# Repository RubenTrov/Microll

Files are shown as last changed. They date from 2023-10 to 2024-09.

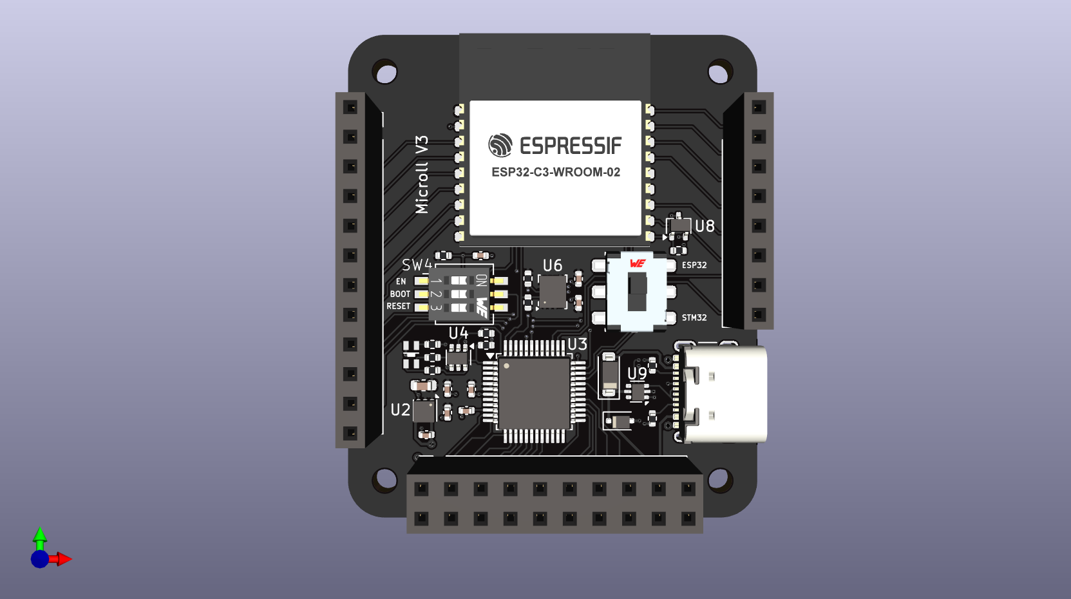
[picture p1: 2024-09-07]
Microll_3D_Front.png

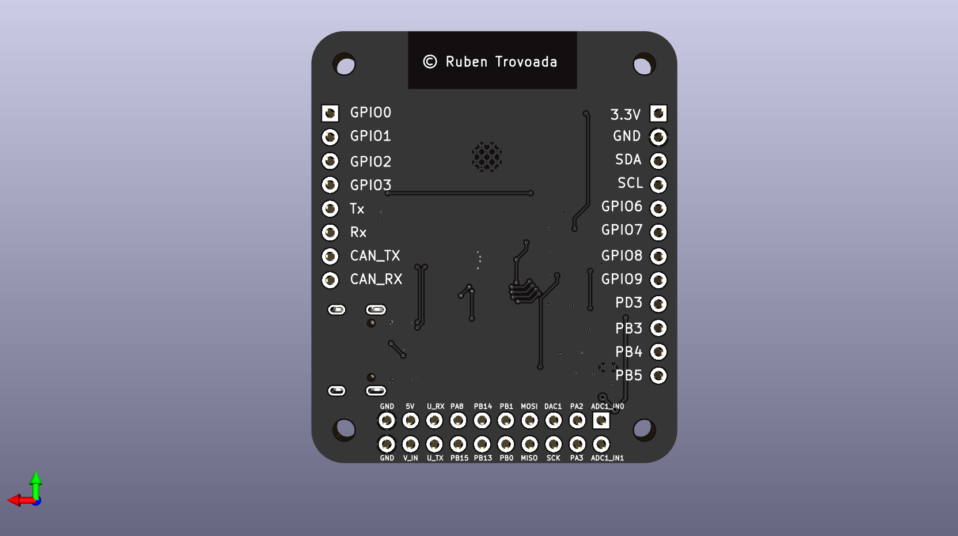
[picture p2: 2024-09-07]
Microll_3D_Back.png

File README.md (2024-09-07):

This is going to be a small PCB with a microcontroller, IMU and a form of wirelessly transmitting that information though wifi/bluetooh.
It will serve as a central piece for a lot of future IoT projects.



#How to program the PCB
This board has two microcontrollers that share the Same USB Port through a switch.
##Programming the STM32
1. The USB selector switch should be flipped to the SM32 position.
2. Open STM32CubeIDE and load the file that you wish to flash to the microcontroller.
3. Set the Boot pin High by setting the Boot on the DIP switch to position 2 and then from the ON side of the switch connect a jumper to the 3.3V GPIO header.
4. Connect the USB to the PCB to power on the board. This should make the STM32 be detected by the programmer.
5. Erase the memory and upload the file.
6. Disconnect the PCB from the USB and switch the position of Boot on the DIP switch.
7. Plug the USB back in the PCB and it will begin executing the program that was uploaded!

##Programming the ESP32
1. You may need to connect the GPIO0 pin to GND using a jumper cable before powering on the board
2. Flip the USB switch to the ESP32 position
3. Flip the EN on the DIP switch to the on position to connect it to 3.3V
4. Power on the board by plugging in the USB
5. Disconnect the GPIO0 pin from GND
6. The board should now be ready to program. Use the editor of your choice for this.

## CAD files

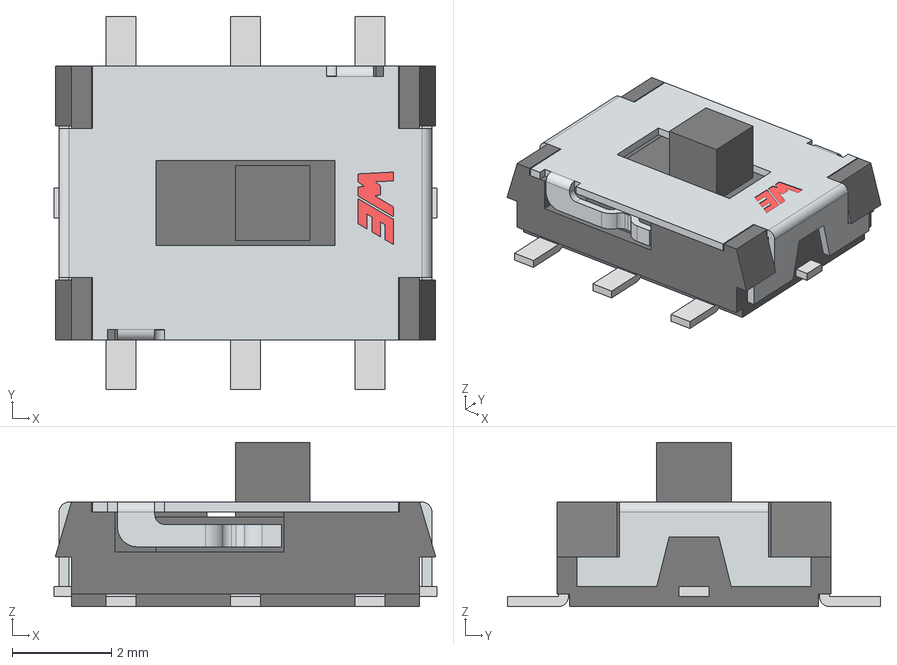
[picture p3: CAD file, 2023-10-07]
3DModels/Download_STP_452403012014 (rev1).stp
7.70 x 7.50 x 3.30 mm
Base
Actuator
cover

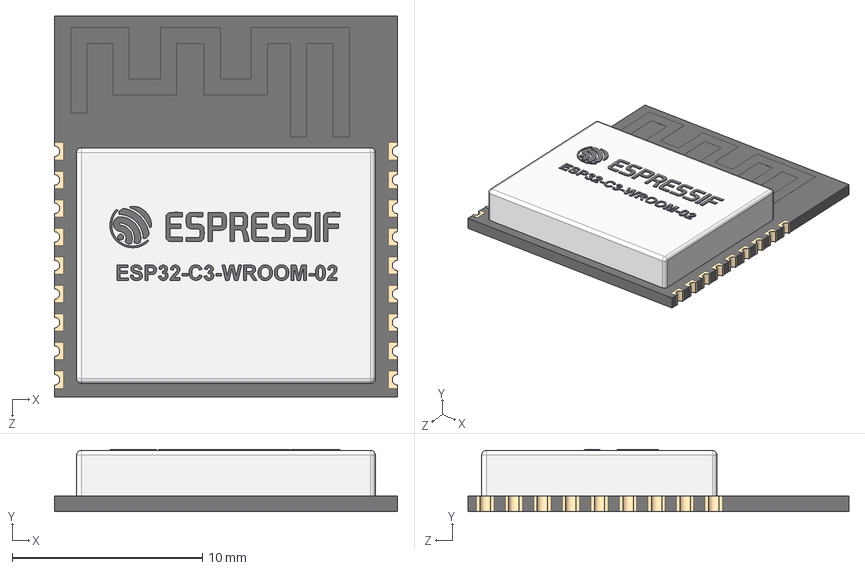
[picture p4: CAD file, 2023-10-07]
3DModels/ESP32-C3-WROOM-02.STEP
18.0 x 3.26 x 20.0 mm

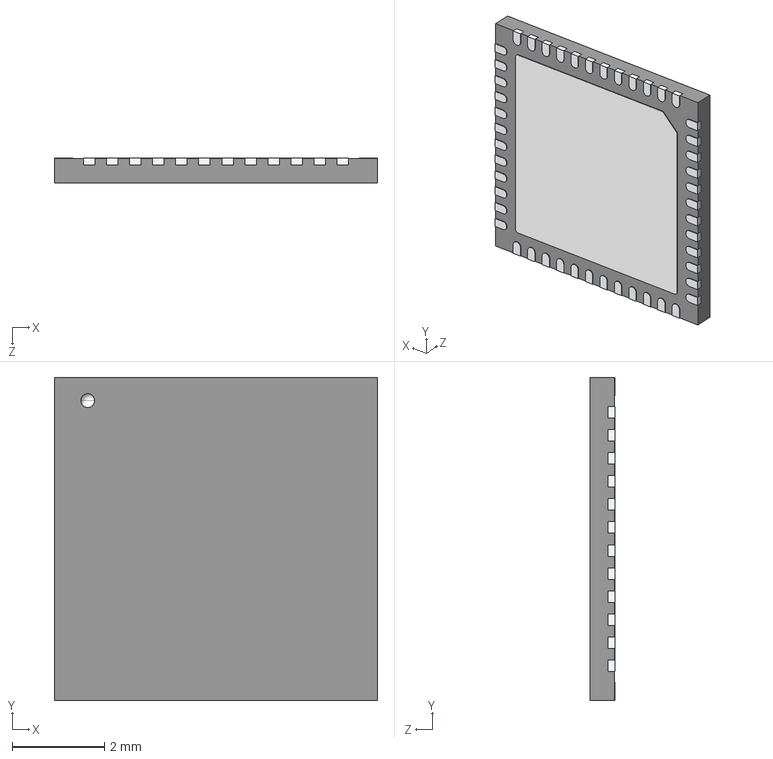
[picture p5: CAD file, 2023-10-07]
3DModels/User Library-UFQFPN48.step
7.00 x 7.00 x 0.55 mm

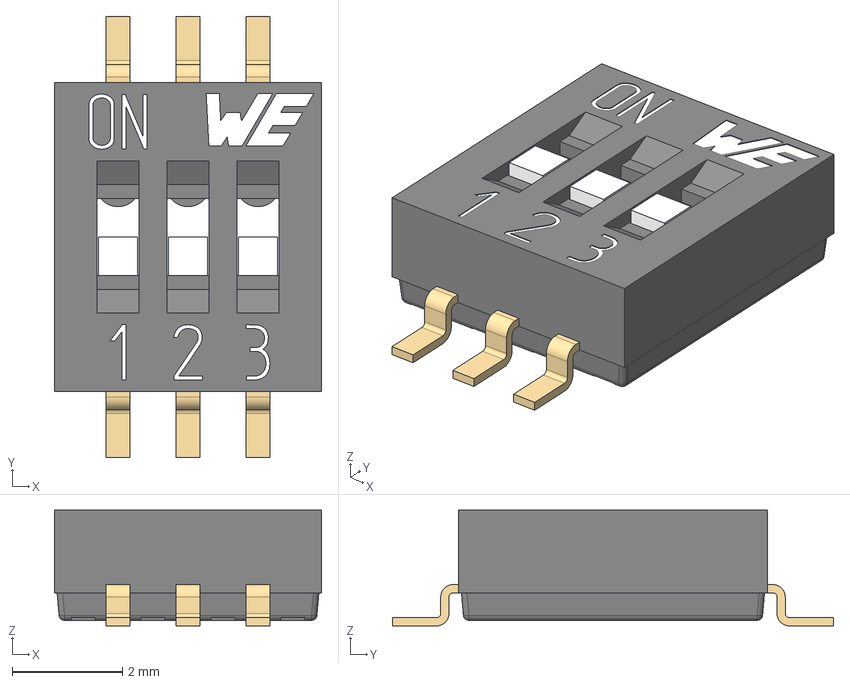
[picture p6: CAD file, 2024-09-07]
3DModels/416131160803 (rev1).stp
4.85 x 8.00 x 2.10 mm

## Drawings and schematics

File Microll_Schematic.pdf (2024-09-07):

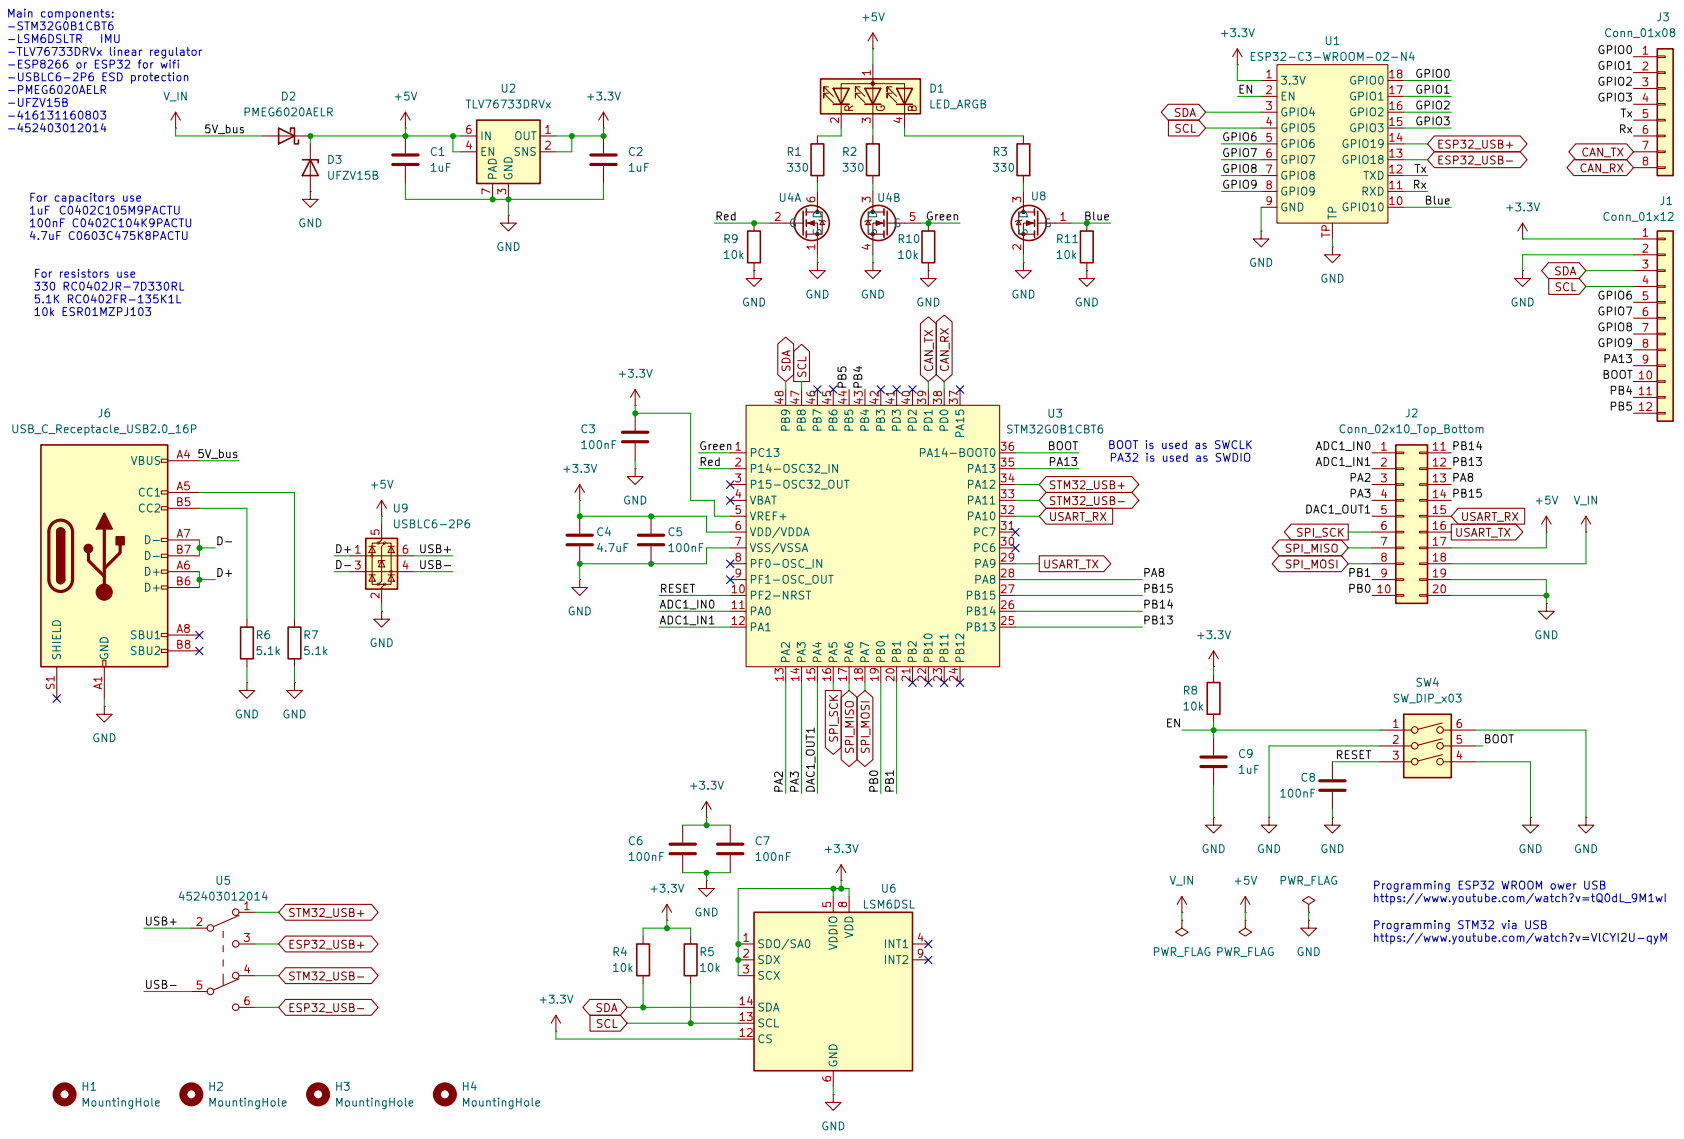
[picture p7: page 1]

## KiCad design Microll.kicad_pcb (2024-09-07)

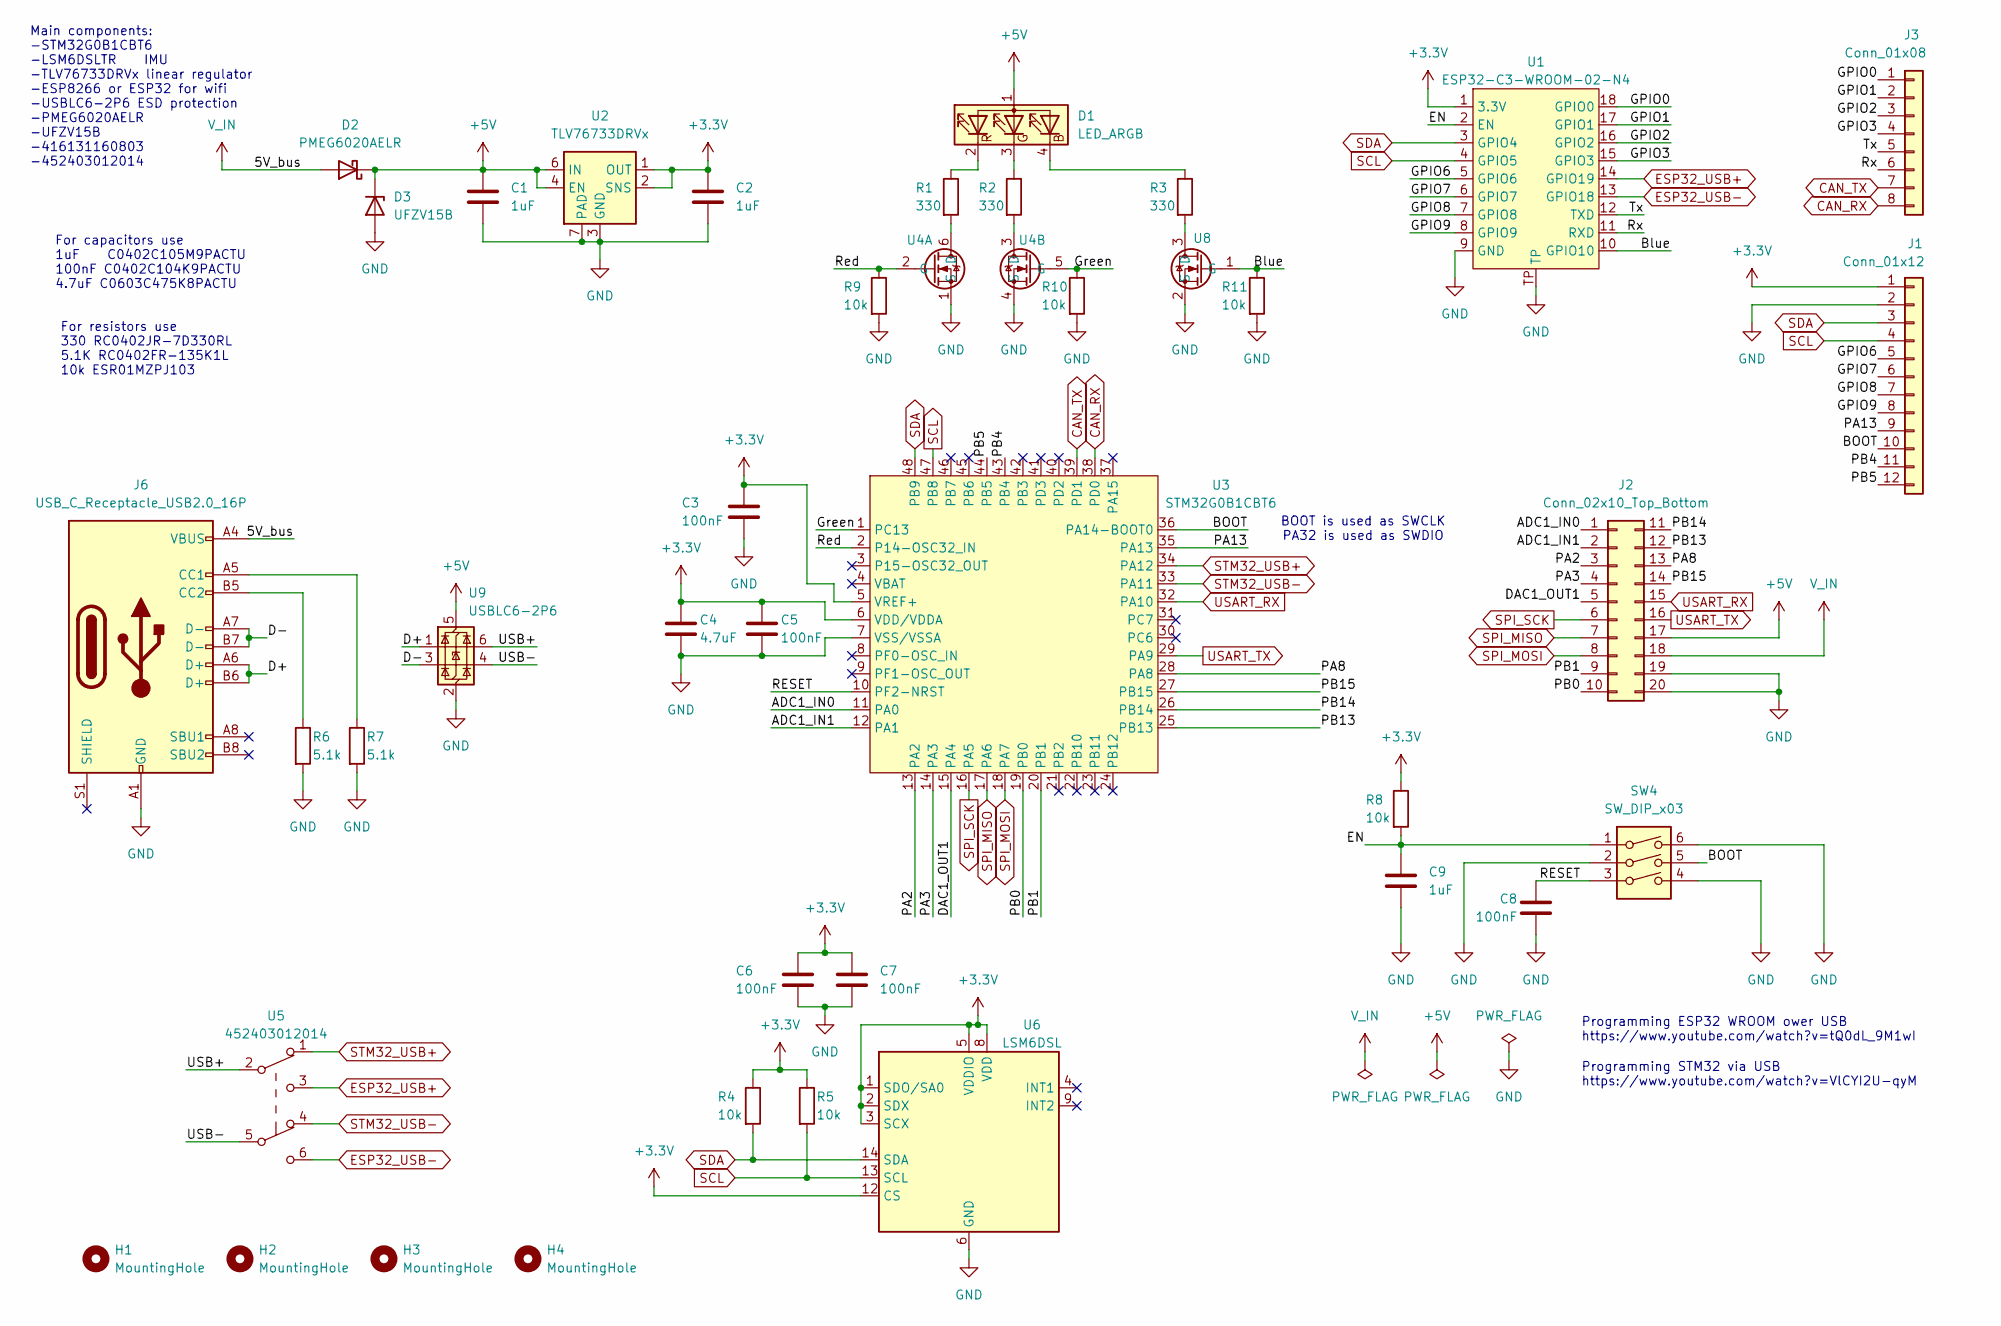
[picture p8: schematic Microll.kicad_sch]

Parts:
C1, C2, C9: 1uF; C_0402_1005Metric
C3, C5, C6, C7, C8: 100nF; C_0402_1005Metric
C4: 4.7uF; C_0603_1608Metric
D1: LED_ARGB; APTF1616LSEEZGKQBKC
D2: PMEG6020AELR; D_SOD-123
D3: UFZV15B; D_SOD-323F
H1, H2, H3, H4: MountingHole; MountingHole_2.2mm_M2
J1: Conn_01x12; PinSocket_1x12_P2.54mm_Vertical
J2: Conn_02x10_Top_Bottom; PinSocket_2x10_P2.54mm_Vertical
J3: Conn_01x08; PinSocket_1x08_P2.54mm_Vertical
J6: USB_C_Receptacle_USB2.0_16P; USB_C_Receptacle_GCT_USB4105-xx-A_16P_TopMnt_Horizontal
R1, R2, R3: 330; R_0402_1005Metric
R4, R5, R8, R9, R10, R11: 10k; R_0402_1005Metric
R6, R7: 5.1k; R_0402_1005Metric
SW4: SW_DIP_x03; WE_DIP_SWITCH_3_POS
U1: ESP32-C3-WROOM-02-N4
U2: TLV76733DRVx; WSON-6-1EP_2x2mm_P0.65mm_EP1x1.6mm_ThermalVias
U3: STM32G0B1CBT6; LQFP-48_7x7mm_P0.5mm
U4: BSD235NH6327XTSA1; SOT-363_SC-70-6
U5: 452403012014; DPDT_Switch_x2
U6: LSM6DSL; LGA-14_3x2.5mm_P0.5mm_LayoutBorder3x4y
U8: NX7002AKW,115; SOT-323_SC-70
U9: USBLC6-2P6; SOT-666

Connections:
+3.3V: C2.1, C3.1, C4.1, C5.1, C6.1, C7.1, J1.1, R4.1, R5.1, R8.1, U1.1 (3.3V), U2.1 (OUT), U2.2 (SNS), U3.5 (VREF+), U3.6 (VDD/VDDA), U6.1 (SDO/SA0), U6.2 (SDX), U6.3 (SCX), U6.5 (VDDIO), U6.8 (VDD), U6.12 (CS)
+5V: C1.1, D1.1 (A), D2.1 (K), D3.1 (K), J2.17, U2.4 (EN), U2.6 (IN), U9.5 (VBUS)
/ADC1_IN0: J2.1, U3.11 (PA0)
/ADC1_IN1: J2.2, U3.12 (PA1)
/BOOT: J1.10, SW4.5, U3.36 (PA14-BOOT0)
/Blue: R11.1, U1.10 (GPIO10), U8.1 (G)
/D+: J6.A6 (D+), J6.B6 (D+), U9.1 (I/O1)
/D-: J6.A7 (D-), J6.B7 (D-), U9.3 (I/O2)
/DAC1_OUT1: J2.5, U3.15 (PA4)
/EN: C9.1, R8.2, SW4.1, U1.2 (EN)
/GPIO0: J3.1, U1.18 (GPIO0)
/GPIO1: J3.2, U1.17 (GPIO1)
/GPIO2: J3.3, U1.16 (GPIO2)
/GPIO3: J3.4, U1.15 (GPIO3)
/GPIO6: J1.5, U1.5 (GPIO6)
/GPIO7: J1.6, U1.6 (GPIO7)
/GPIO8: J1.7, U1.7 (GPIO8)
/GPIO9: J1.8, U1.8 (GPIO9)
/Green: R10.1, U3.1 (PC13), U4.5 (G)
/PA2: J2.3, U3.13 (PA2)
/PA3: J2.4, U3.14 (PA3)
/PA8: J2.13, U3.28 (PA8)
/PA13: J1.9, U3.35 (PA13)
/PB0: J2.10, U3.19 (PB0)
/PB1: J2.9, U3.20 (PB1)
/PB4: J1.11, U3.43 (PB4)
/PB5: J1.12, U3.44 (PB5)
/PB13: J2.12, U3.25 (PB13)
/PB14: J2.11, U3.26 (PB14)
/PB15: J2.14, U3.27 (PB15)
/RESET: C8.1, SW4.3, U3.10 (PF2-NRST)
/Red: R9.1, U3.2 (P14-OSC32_IN), U4.2 (G)
/Rx: J3.6, U1.11 (RXD)
/Tx: J3.5, U1.12 (TXD)
/USB+: U5.2, U9.6 (I/O1)
/USB-: U5.5, U9.4 (I/O2)
CAN_RX: J3.8, U3.38 (PD0)
CAN_TX: J3.7, U3.39 (PD1)
ESP32_USB+: U1.14 (GPIO19), U5.3
ESP32_USB-: U1.13 (GPIO18), U5.6
GND: C1.2, C2.2, C3.2, C4.2, C5.2, C6.2, C7.2, C8.2, C9.2, D3.2 (A), J1.2, J2.19, J2.20, J6.A1 (GND), J6.A12 (GND), J6.B1 (GND), J6.B12 (GND), R6.2, R7.2, R9.2, R10.2, R11.2, SW4.2, SW4.4, SW4.6, U1.9 (GND), U1.TP, U2.3 (GND), U2.5 (GND), U2.7 (PAD), U3.7 (VSS/VSSA), U4.1 (S), U4.4 (S), U6.6 (GND), U6.7 (GND), U8.2 (S), U9.2 (GND)
unnamed: D1.4 (BK), R3.1
unnamed: D1.3 (GK), R2.1
unnamed: D1.2 (RK), R1.1
unnamed: J6.A5 (CC1), R7.1
unnamed: J6.B5 (CC2), R6.1
unnamed: R1.2, U4.6 (D)
unnamed: R2.2, U4.3 (D)
unnamed: R3.2, U8.3 (D)
SCL: J1.4, R5.2, U1.4 (GPIO5), U3.47 (PB8), U6.13 (SCL)
SDA: J1.3, R4.2, U1.3 (GPIO4), U3.48 (PB9), U6.14 (SDA)
SPI_MISO: J2.7, U3.17 (PA6)
SPI_MOSI: J2.8, U3.18 (PA7)
SPI_SCK: J2.6, U3.16 (PA5)
STM32_USB+: U3.34 (PA12), U5.1
STM32_USB-: U3.33 (PA11), U5.4
USART_RX: J2.15, U3.32 (PA10)
USART_TX: J2.16, U3.29 (PA9)
V_IN: D2.2 (A), J2.18, J6.A4 (VBUS), J6.A9 (VBUS), J6.B4 (VBUS), J6.B9 (VBUS)

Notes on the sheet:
Programming ESP32 WROOM ower USB https://www.youtube.com/watch?v=tQ0dL_9M1wI
Programming STM32 via USB https://www.youtube.com/watch?v=VlCYI2U-qyM
For capacitors use 1uF C0402C105M9PACTU 100nF C0402C104K9PACTU 4.7uF C0603C475K8PACTU
BOOT is used as SWCLK PA32 is used as SWDIO
Main components: -STM32G0B1CBT6 -LSM6DSLTR IMU -TLV76733DRVx linear regulator -ESP8266 or ESP32 for wifi -USBLC6-2P6 ESD protection -PMEG6020AELR -UFZV15B -416131160803 -452403012014
For resistors use 330 RC0402JR-7D330RL 5.1K RC0402FR-135K1L 10k ESR01MZPJ103

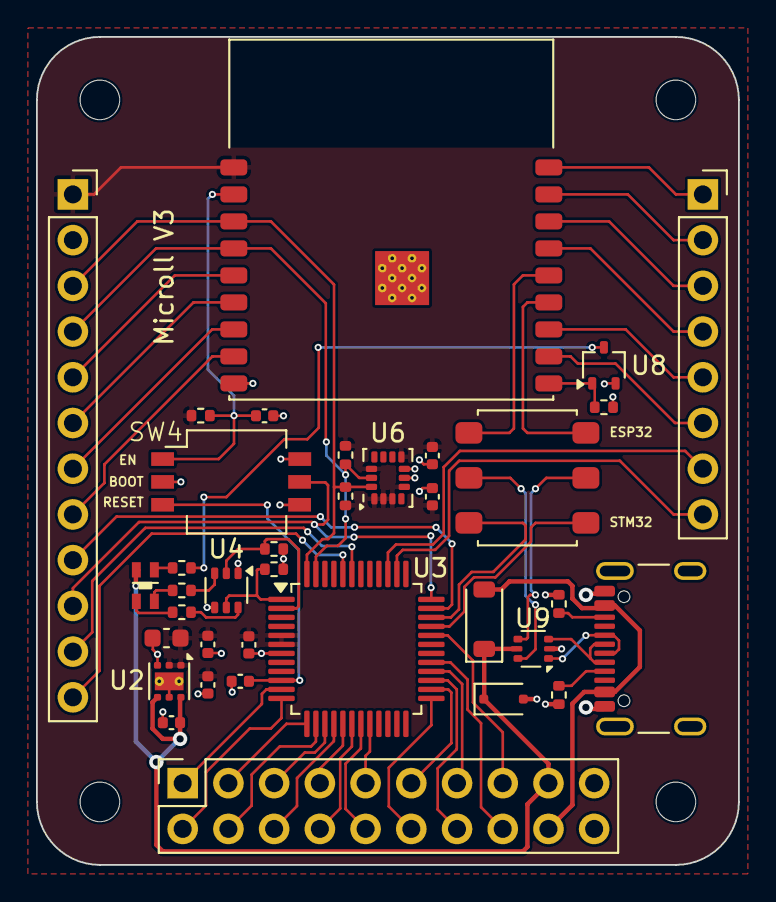
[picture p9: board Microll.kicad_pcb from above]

Board: 2 copper layers, 39.0 x 46.0 mm, 40 parts (0 on the bottom side), 59 nets.

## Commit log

2023-09-10 Initial project creation
    [Microll.kicad_pcb, Microll.kicad_sch]
2023-09-10 Initial part selection
    [Microll.kicad_sch]
2023-09-11 More motes on the board main components.
    [Microll.kicad_sch]
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2023-09-17 Finished footprint for ESP32
    [Microll.kicad_sch]
2023-09-17 Added linear regulator symbol and footprint.
    [Microll.kicad_sch]
2023-09-24 Decided on STM32 microcontroller and made footprint and symbol
    [Microll.kicad_sch]
2023-09-25 Added IMU. Initial placement of components on PCB to check spacing
    [Microll.kicad_pcb, Microll.kicad_sch]
2023-09-27 Added some notes on programming the STM32 and ESP32 over USB. Added datasheets to all components.
    [Microll.kicad_sch]
2023-10-01 Begun drafting linear regulator circuit and passive components
    [Microll.kicad_sch]
2023-10-01 Thinking of swapping out linear regulator. Thinking about programming jumper to swap between microcontrollers
    [Microll.kicad_sch]
2023-10-03 Changed linear regulator to TLV767
    [Microll.kicad_sch]
2023-10-03 added some capacitors to the IMU
    [Microll.kicad_sch]
2023-10-07 Added 3D models to all PCB components. Added switch for USB programming between microcontrollers
    [Download_STP_452403012014 (rev1).stp, ESP32-C3-WROOM-02.STEP, Microll.kicad_pcb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]
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2023-10-10 Corrected mistake in usb wiring to switch
    [Microll.kicad_sch]
2023-10-10 Added ESD protection, decoupling capacitors and new footprints
    [Microll.kicad_pcb, Microll.kicad_sch]
2023-10-15 Added an RGB LED and solder jumpers for the EN and Boot pins of the microcontrollers in case I need to do something woth programming
    [Microll.kicad_sch]
2023-10-15 Added nets to the LEDs. Pretty much all that is left in the scematic is adding the I/O pins and then it's off to the PCB layout
    [Microll.kicad_pcb, Microll.kicad_sch]
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2023-12-23 Initial placement for the PCB.
    [Microll.kicad_pcb, Microll.kicad_sch]
2023-12-25 Updated STMew and ESP32 symbols with correct pins. Need to update USB-C next.
    [Microll.kicad_pcb, Microll.kicad_sch]
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2024-01-13 USB-C footprint should now match schematic
    [Microll.kicad_pcb, Microll.kicad_sch]
2024-01-13 Organised board sape and pin headers.
    [Microll.kicad_pcb, Microll.kicad_sch]
2024-01-13 Board ready for track routing
    [Microll.kicad_pcb]
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2024-01-27 finished routing. Need to clear DRC errors
    [Microll.kicad_pcb, Microll.kicad_sch]
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2024-01-28 Added 3D model for USB-C. PCB finished!
    [1054500101.stp, Microll.kicad_pcb]
2024-01-28 PCB finished and ordered
    [Microll.kicad_pcb]
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2024-02-16 Lots of notes on what to improve for the next one
    [Microll-B_Cu.gbr, Microll-B_Mask.gbr, Microll-B_Paste.gbr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]
2024-02-16 Added 5.1k resistors to USBC for 5V
    [Microll.kicad_sch]
2024-02-16 Fixed mistake on PA13 mixing it up with the boot button.
    [Microll.kicad_sch]
2024-02-16 Changed the enable pin for the ESP32 to a button. adding extra row of IO pins
    [Microll.kicad_sch]
2024-02-16 adding second regulator for input voltage through GPIO
    [Microll.kicad_sch]
2024-02-17 Added note to simulate reverse polarity protection diode
    [Microll.kicad_sch]
2024-02-18 It was fine before but now properly following schematic pin recomended for USBLC ESD protection
    [Microll.kicad_sch]
2024-02-18 corrected big mistake on 3.3V regulator sns pin
    [Microll.kicad_sch]
2024-02-18 added input protection diodes. starting new pcb layout
    [Microll.kicad_pcb, Microll.kicad_sch]
2024-02-19 Removed unnecessary 5V regulator
    [Microll.kicad_pcb, Microll.kicad_sch]
2024-02-19 Changed connectors to two rows to conserve board space. Still considering getting another secondary boltage regulator for powering external motors
    [Microll.kicad_pcb, Microll.kicad_sch]
2024-02-21 Begun placement for new Microll PCB
    [Microll.kicad_pcb]
2024-02-22 Updated breakout pinout and placement
    [Microll.kicad_pcb, Microll.kicad_sch]
2024-02-24 Converted to KiCad 8.0
    [Microll.kicad_pcb, Microll.kicad_sch]
2024-02-25 Changed the programming switches to a more compact dip format to save board space
    [Microll.kicad_pcb, Microll.kicad_sch]
2024-03-01 Board outline defined. Initial routing comenced
    [Microll.kicad_pcb, Microll.kicad_sch]
2024-03-01 Additional routing. Need to update power symbols due tto kicad 8. Need to add 4 pins from STM32
    [Microll.kicad_pcb, Microll.kicad_sch]
2024-03-01 Largely finishhed routing. Need to sort out 3D model for USBC and add silk skreen pin labels to underside of board
    [Microll.kicad_pcb, Microll.kicad_sch]
2024-03-01 Updated USBC. Just need to add silkscreen to te bottom 12 pin connector and it's done
    [Microll.kicad_pcb, Microll.kicad_sch]
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2024-03-12 Fixed typo on STM32 symbol pinout
    [Microll.kicad_sch]
2024-03-26 Updated gitignore to ignore PCB lock. Tidy up schematic notes
    [Microll.kicad_sch]
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2024-04-03 Messed up on the boot option pin and didn't connect it to +3.3V on the other side.. Added a note
    [Microll.kicad_sch]
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2024-04-20 SWDIO and SWCLK now accessible through gpio pins. Microcontroller changed to more solder friendly package
    [Microll.kicad_pcb, Microll.kicad_sch]
2024-04-21 Made Microll V2 and updated Gerber Files
    [Microll-B_Cu.gbr, Microll-B_Mask.gbr, Microll-B_Paste.gbr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]
2024-09-02 Realized why I kept killing both the STM32 and ESP32. I stupidly connected the LEDs to 5V and was having the microcontrollers sink that. The micorcontroller pins can only handle 3.6V max. Even with t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
    [Microll.kicad_sch]
2024-09-03 small notes added on what will be changed. Schematic doc includes revision
    [Microll.kicad_sch]
2024-09-04 Added NMOS to control the LEDs. Changed the series resistance to set the appropriate current limit for the LEDs. Updated USB ESD protection. Added Simulations folder with LED simulation.
    [Microll.kicad_sch]
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2024-09-07 Added datasheets to components. Ready to proceed with layout update
    [Microll.kicad_sch]
2024-09-07 Updated PCB to Microll V3
    [416131160803 (rev1).stp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]
2024-09-07 Updated Gerber files. Added 3D photos and schematic PDF
    [Microll-B_Cu.gbr, Microll-B_Mask.gbr, Microll-B_Paste.gbr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]

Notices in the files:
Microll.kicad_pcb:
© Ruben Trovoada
